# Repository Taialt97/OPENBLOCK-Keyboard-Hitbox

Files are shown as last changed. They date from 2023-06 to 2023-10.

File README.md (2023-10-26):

 

>:warning: This project is currently under development; the PCBs have not been tested and may require additional optimization.

# Introduction
This project aims to create an open-source, modular, and easy-to-understand design for a Hit Box layout using the Raspberry Pi (RP2040) as the core. My goal is to make the project as accessible and customizable as possible, providing everyone with the flexibility to adapt the design to their specific needs.

downImg
downImg(2)

## Chip Compatibility
- **GP2040 chip**: Offers higher compatibility with PC, PS4, PS3, Switch, and Xbox.

| ProMicro (Mega32U4) | RespbarryPie (GP2040) | NameOfSwitch | Action | PlayStation | Xbox |
|---|---|---|---|---|---|
| 6 | 6 | MX10 | Up | Dpad Up | Dpad Up | | |
| 14 | 20 | MX2 | Down |Dpad Down | Dpad Down | | |
| 16 | 23 | MX1 | Left | Dpad Left | Dpad Left | | |
| 15 | 22 | MX3 | Right | Dpad Right | Dpad Right | | |
| 21 | 29 | MX4 | Light Punch | Square | X | | |
| 5 | 5 | MX11 | Light Kick  | X | A | | |
| 4 | 4 | MX5 | Medium Punch| Circle | B | | |
| 20 | 28 | MX12 | Medium Kick | Triangle | Y | | |
| 18 | 26 | MX6 | Heavy Punch | L1 | LB | | |
| 19 | 27 | MX13 | Heavy Kick  | R1 | RB | | |
| 2 | 2 | MX7 | Triple Punch| L2 | LT | | |
| 3 | 3 | MX14 | Triple Kick | R2 | RT | | |
| 8 | 8 | MX8 | Select 1 | Select | Back | | |
| 7 | 7 | MX9 | Select 2 | Start | Start | | |

# Costs
The cost to build the fight-stick will depend on parts, shipping, and tools. Below is a breakdown:

1. PCB (minimum order of 5) without shipping: **$8**. Shipping will vary by location and method.
2. Parts for PCB assembly: **$25** (hot swap sockets, keys, switches, Pro Micro, and IC Sockets).
3. Tools: Varies widely, but a cost-effective approach is possible.

## Part List
### Micro Chips List
Below is a list of top-tier microcontrollers that I've found to be the best in the market. While more cost-effective alternatives are available from sites like Aliexpress (which I've personally tested and found satisfactory), the following options are slightly more expensive but come with a guarantee of proper functionality.

If you're using a different 12-pin microcontroller that you think should be included here, feel free to leave a comment!

1. [Elite-Pi - USB-C Pro Micro Replacement RP2040 Controller](https://keeb.io/collections/diy-parts/products/elite-pi-usb-c-pro-micro-replacement-rp2040)
2. [SparkFun Pro Micro - RP2040](https://www.sparkfun.com/products/18288)

### Parts List
To ensure affordability, I've listed essential parts and some alternatives:

- PCB | $8 (without shipping)
- (optional) Hot-swappable PCB socket | $3
- Keycaps | $5-$15 (depends on quality)
- Switch | $5-$50 (depends on the manufacturer and "quality" of the switch)
- Pro Micro | $4-$30 (ensure the chip is **RP2040**)

### Recommended
- KESTER SOLDER | $35-$60 (quality soldering wire)
- PINECIL – Smart Mini Portable Soldering Iron (Version 2) | $25.99-$35.99

# Code

Upon connecting the microcontroller to your computer, a new drive will appear. 
- Drag the `nuke.h` file into this drive; the microcontroller will disconnect and then reconnect.
- Drag the `OpenBlock.h` file into the drive. You'll hear a sound indicating that the drive has disconnected and reconnected.

To test your controller, visit the [Gamepad Tester Website](https://hardwaretester.com/gamepad).
For modifying the code or creating new code, go to the [GP2040-CE](https://gp2040-ce.info/#/) website.
There, you'll find all the resources you need to customize or create new code. If you have any questions, refer to our [Discord channel](https://discord.gg/kJDAZVwU) — they're awesome!

# Note
This project is an open-source initiative, designed for modularity and ease of understanding. Contributions and suggestions from the community are welcome, fostering collaboration and growth.

# Sponsorship
This repository is sponsored by [PCBWay](https://www.pcbway.com/).
PCBWay (https://www.pcbway.com/)
PCBWay specializes in manufacturing high-quality PCBs. They offer a range of services including PCB prototyping, assembly, and much more. We are grateful for their support in making this project possible.
Simplify Your Custom PCB Orders with PCBWay

Ordering custom PCBs has never been easier, thanks to PCBWay's intuitive platform. With the 'Instant Quote' feature, you can swiftly enter crucial information such as PCB type, dimensions, and material. Plus, helpful tooltips and guides are there to assist you every step of the way.
Unmatched Verification Process

What sets PCBWay apart is their meticulous verification process. Once you upload your Gerber files, a team of experts scrutinizes them for any errors or omissions. You'll be promptly notified of any issues via email or directly on the platform, ensuring a nearly error-free process.
Real-Time Project Tracking

PCBWay takes your experience up a notch by offering real-time project tracking. This level of transparency allows you to better manage your project timelines and make well-informed decisions.
Reliable and Fast Shipping

When it's time to ship, PCBWay provides trustworthy options like DHL, FedEx, and OCS. Need it fast? Expedited shipping is available right from the get-go. In a recent test run, the entire process—from uploading the Gerber files to receiving the finished PCBs—took just six days.
Conclusion

PCBWay is a top choice for anyone transitioning from generic to custom PCBs. The platform excels in ease of use, quality control, and speed, making it ideal for specialized projects.
For more information, visit their [website](https://www.pcbway.com/).

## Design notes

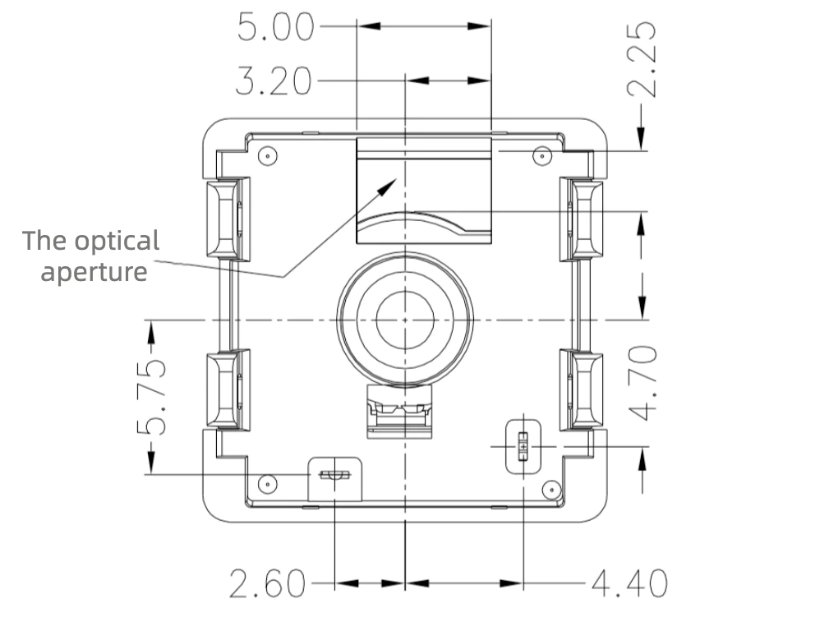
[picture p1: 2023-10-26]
Open-Block RP2040 Gateron Only Low Profile/Kicad Files/gateron-low-profile-mechanical-switch-pcb-of-layout.webp

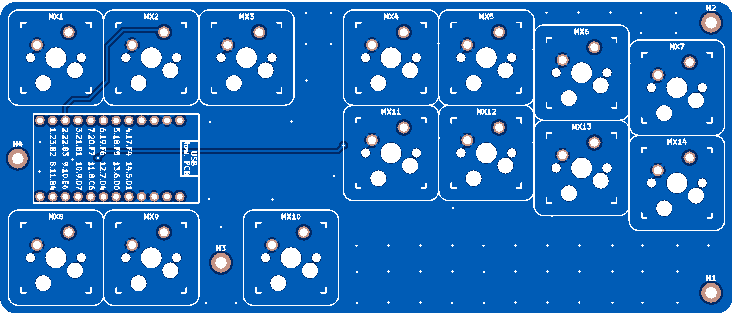
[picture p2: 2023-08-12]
Open-Block RP2040 High Profile/Images/Top.png

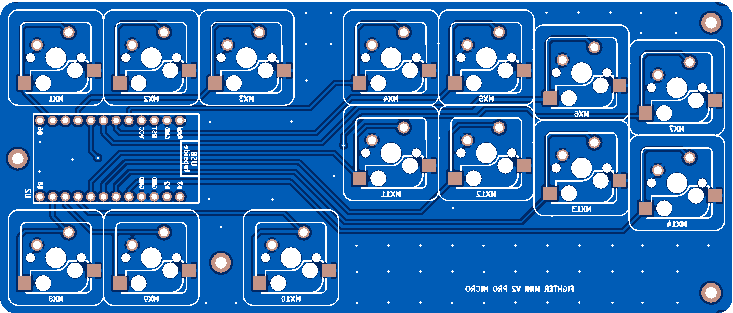
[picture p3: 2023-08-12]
Open-Block RP2040 High Profile/Images/Bottom.png

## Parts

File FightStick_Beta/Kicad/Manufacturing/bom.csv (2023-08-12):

Designator | Footprint | Quantity | Value | LCSC Part #
C2 | 0805 | 1 | 4.7uF | CC0805ZRY5V6BB475
C3 | 0805 | 1 | 0.1uF | CC0805ZRY5V6BB475
D1, D10, D11, D12, D13, D14, D2, D3, D4, D5, D6, D7, D8, D9 | D_SOD-123 | 14 | 1N4448W-TP | 1N4448W-TP
H1, H2, H3 | MountingHole_4.3mm_M4 | 3 | MountingHole
J1 | JST_PH_B2B-PH-K_1x02_P2.00mm_Vertical | 1 | B2B-PH-K-S(LF)(SN) | B2B-PH-K-S(LF)(SN)
MX1, MX10, MX11, MX12, MX13, MX14, MX2, MX3, MX4, MX5, MX6, MX7, MX8, MX9 | Kailh_socket_MX_optional | 14 | MX_SW_solder
R3 | 0805 | 1 | 100k | RC0805JR-07100KL
SW2 | SW_EG2208 | 1 | EG2208
U1 | ArduinoProMicro | 1 | ProMicro

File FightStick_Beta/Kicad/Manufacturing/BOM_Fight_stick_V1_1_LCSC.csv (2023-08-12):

Designator | Footprint | Quantity | Value | Part # | LCSC Part #
C2 | 805 | 1 | 4.7uF | CC0805KKX7R8BB475 | C354262
C3 | 805 | 1 | 0.1uF | CC0805KRX7R9BB104 | C49678
D1, D10, D11, D12, D13, D14, D2, D3, D4, D5, D6, D7, D8, D9 | D_SOD-123 | 14 | 1N4448W-TP | 1N4448W-TP | C668855
J1 | JST_PH_B2B-PH-K_1x02_P2.00mm_Vertical | 1 | B2B-PH-K-S(LF)(SN) | B2B-PH-K-S(LF)(SN) | C131337
MX1, MX10, MX11, MX12, MX13, MX14, MX2, MX3, MX4, MX5, MX6, MX7, MX8, MX9 | Kailh_socket_MX_optional | 14 | MX_SW_solder | Kailh CPG151101D212 | C400234
R3 | 805 | 1 | 100k | RC0805FR-07100KL | C96346
SW2 | SW_EG2208 | 1 | EG2208 |  | C609827
U1 | ArduinoProMicro | 1 | ProMicro | custom module

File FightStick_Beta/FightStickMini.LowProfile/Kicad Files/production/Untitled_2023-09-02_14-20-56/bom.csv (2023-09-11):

Designator | Footprint | Quantity | Value | LCSC Part #
H1, H2, H3, H4 | MountingHole_2.2mm_M2_DIN965_Pad | 4 | MountingHole
MX1, MX10, MX11, MX12, MX13, MX14, MX2, MX3, MX4, MX5, MX6, MX7, MX8, MX9 | Kailh_socket_PG1350_optional | 14 | MX_SW_HS

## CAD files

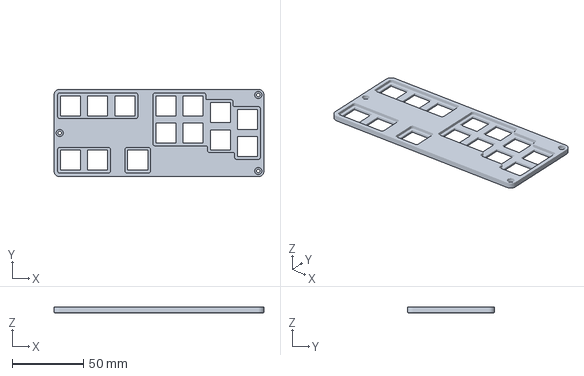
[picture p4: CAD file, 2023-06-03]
FightStick_Beta/Fusion 360/Plate.3mf
146.9 x 61.1 x 4.00 mm

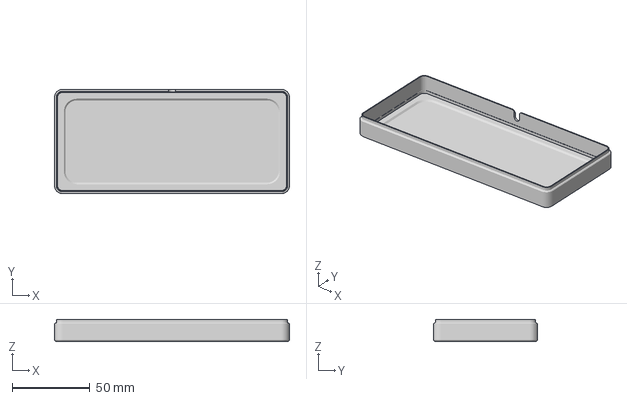
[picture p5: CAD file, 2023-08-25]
Open-Block RP2040 High Profile/3DFiles/BottomCase.3mf
151.2 x 67.1 x 14.3 mm

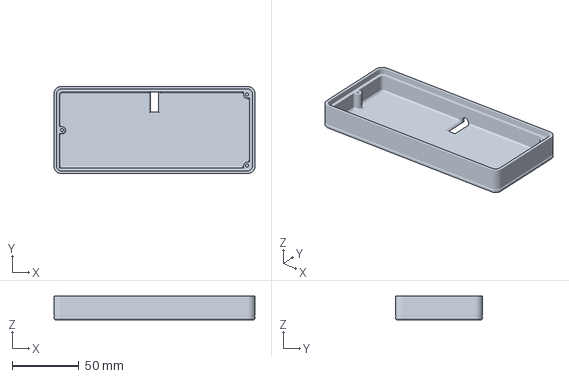
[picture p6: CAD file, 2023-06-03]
FightStick_Beta/Fusion 360/Case.3mf
150.9 x 65.1 x 18.0 mm

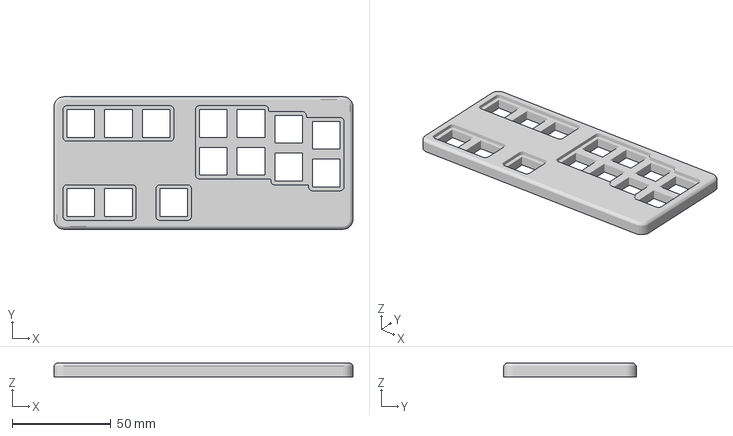
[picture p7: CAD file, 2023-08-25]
Open-Block RP2040 High Profile/3DFiles/TopCase.3mf
151.2 x 67.1 x 7.00 mm

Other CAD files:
FightStick_Beta/Fusion 360/Case.stl
FightStick_Beta/Fusion 360/Fight Stick Fusion 360.f3d
FightStick_Beta/Fusion 360/Plate.stl
Open-Block RP2040 High Profile/3DFiles/FightStickMiniCase.f3z

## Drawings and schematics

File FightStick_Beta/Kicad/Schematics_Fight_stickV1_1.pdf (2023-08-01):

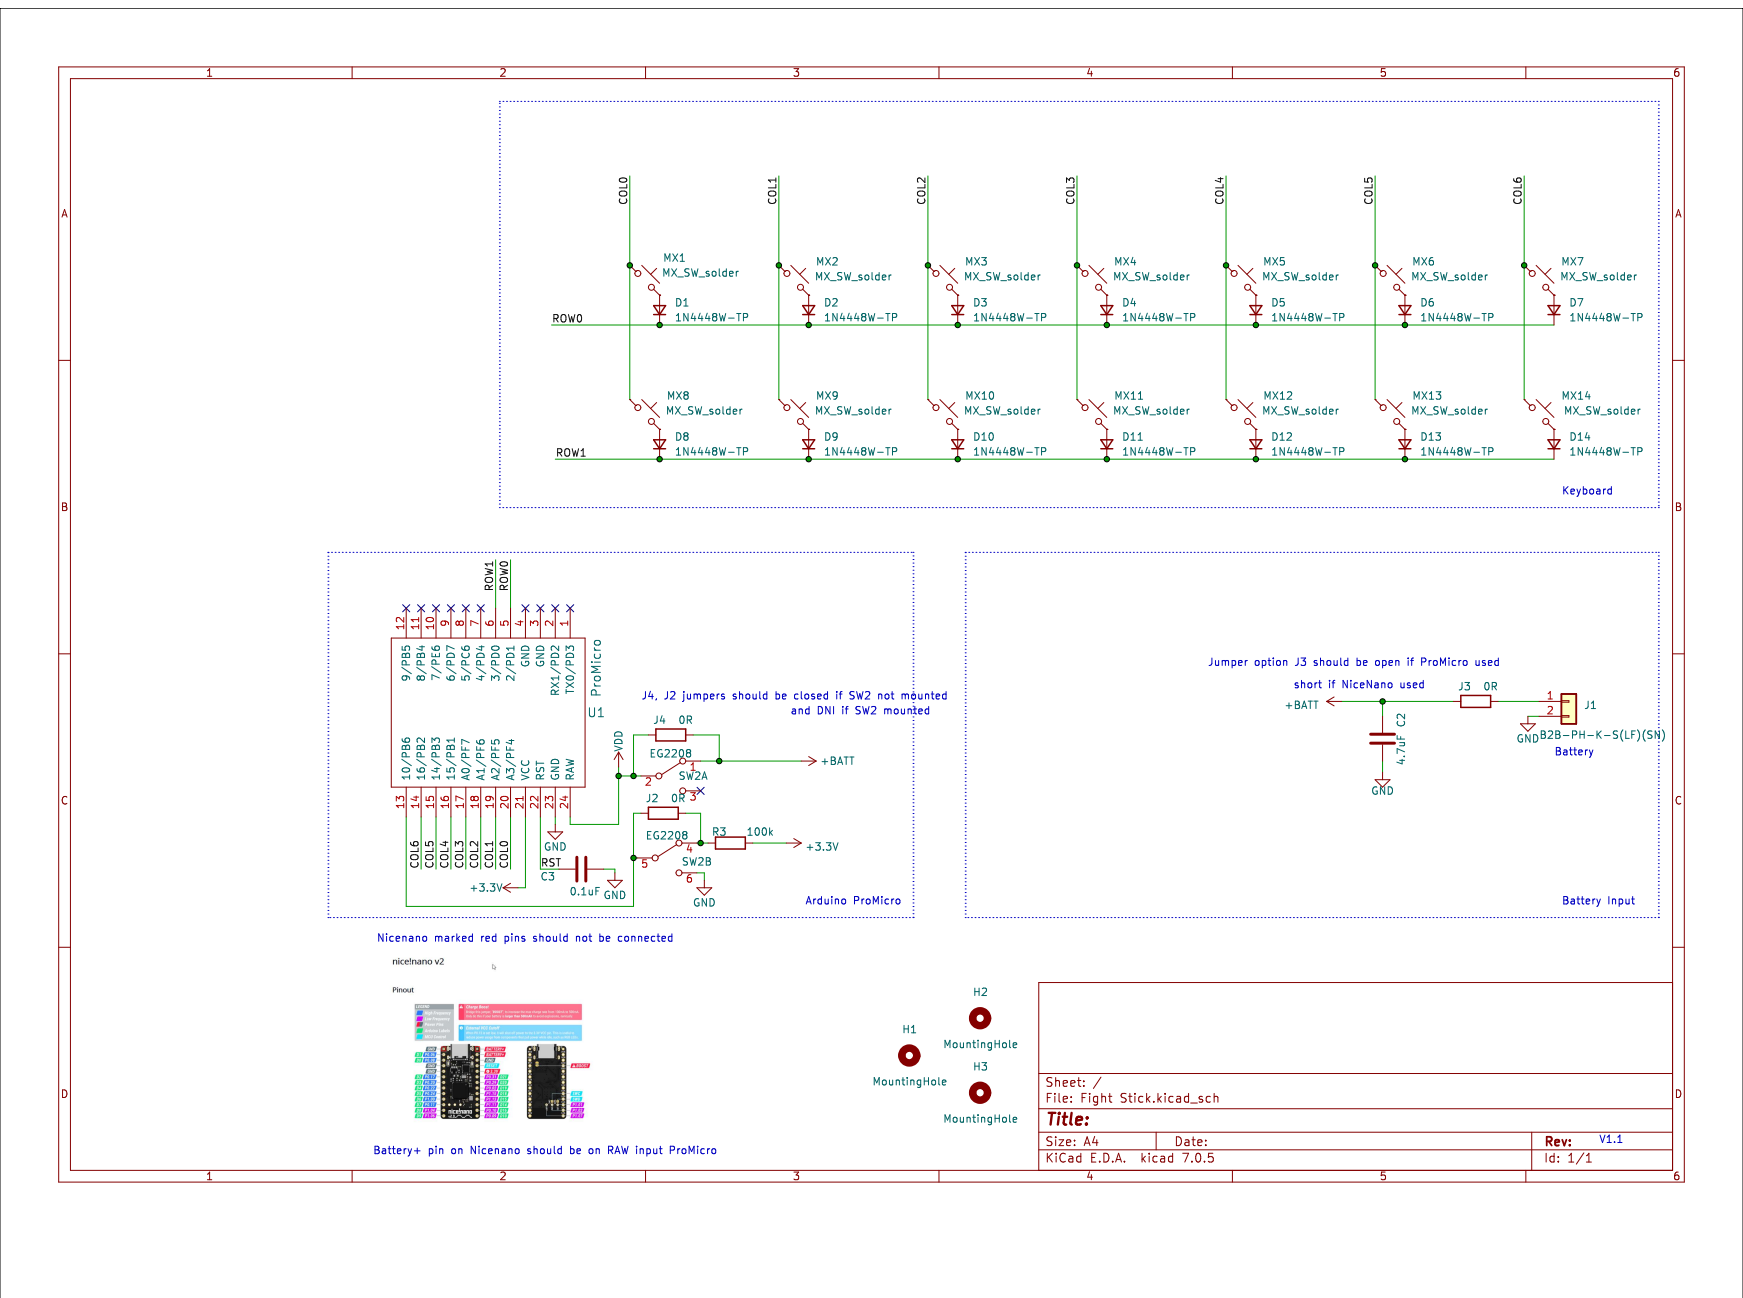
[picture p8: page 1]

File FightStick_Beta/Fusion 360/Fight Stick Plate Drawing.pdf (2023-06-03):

61.15 137.82

52.1 A A (2:1) | 14 TYP

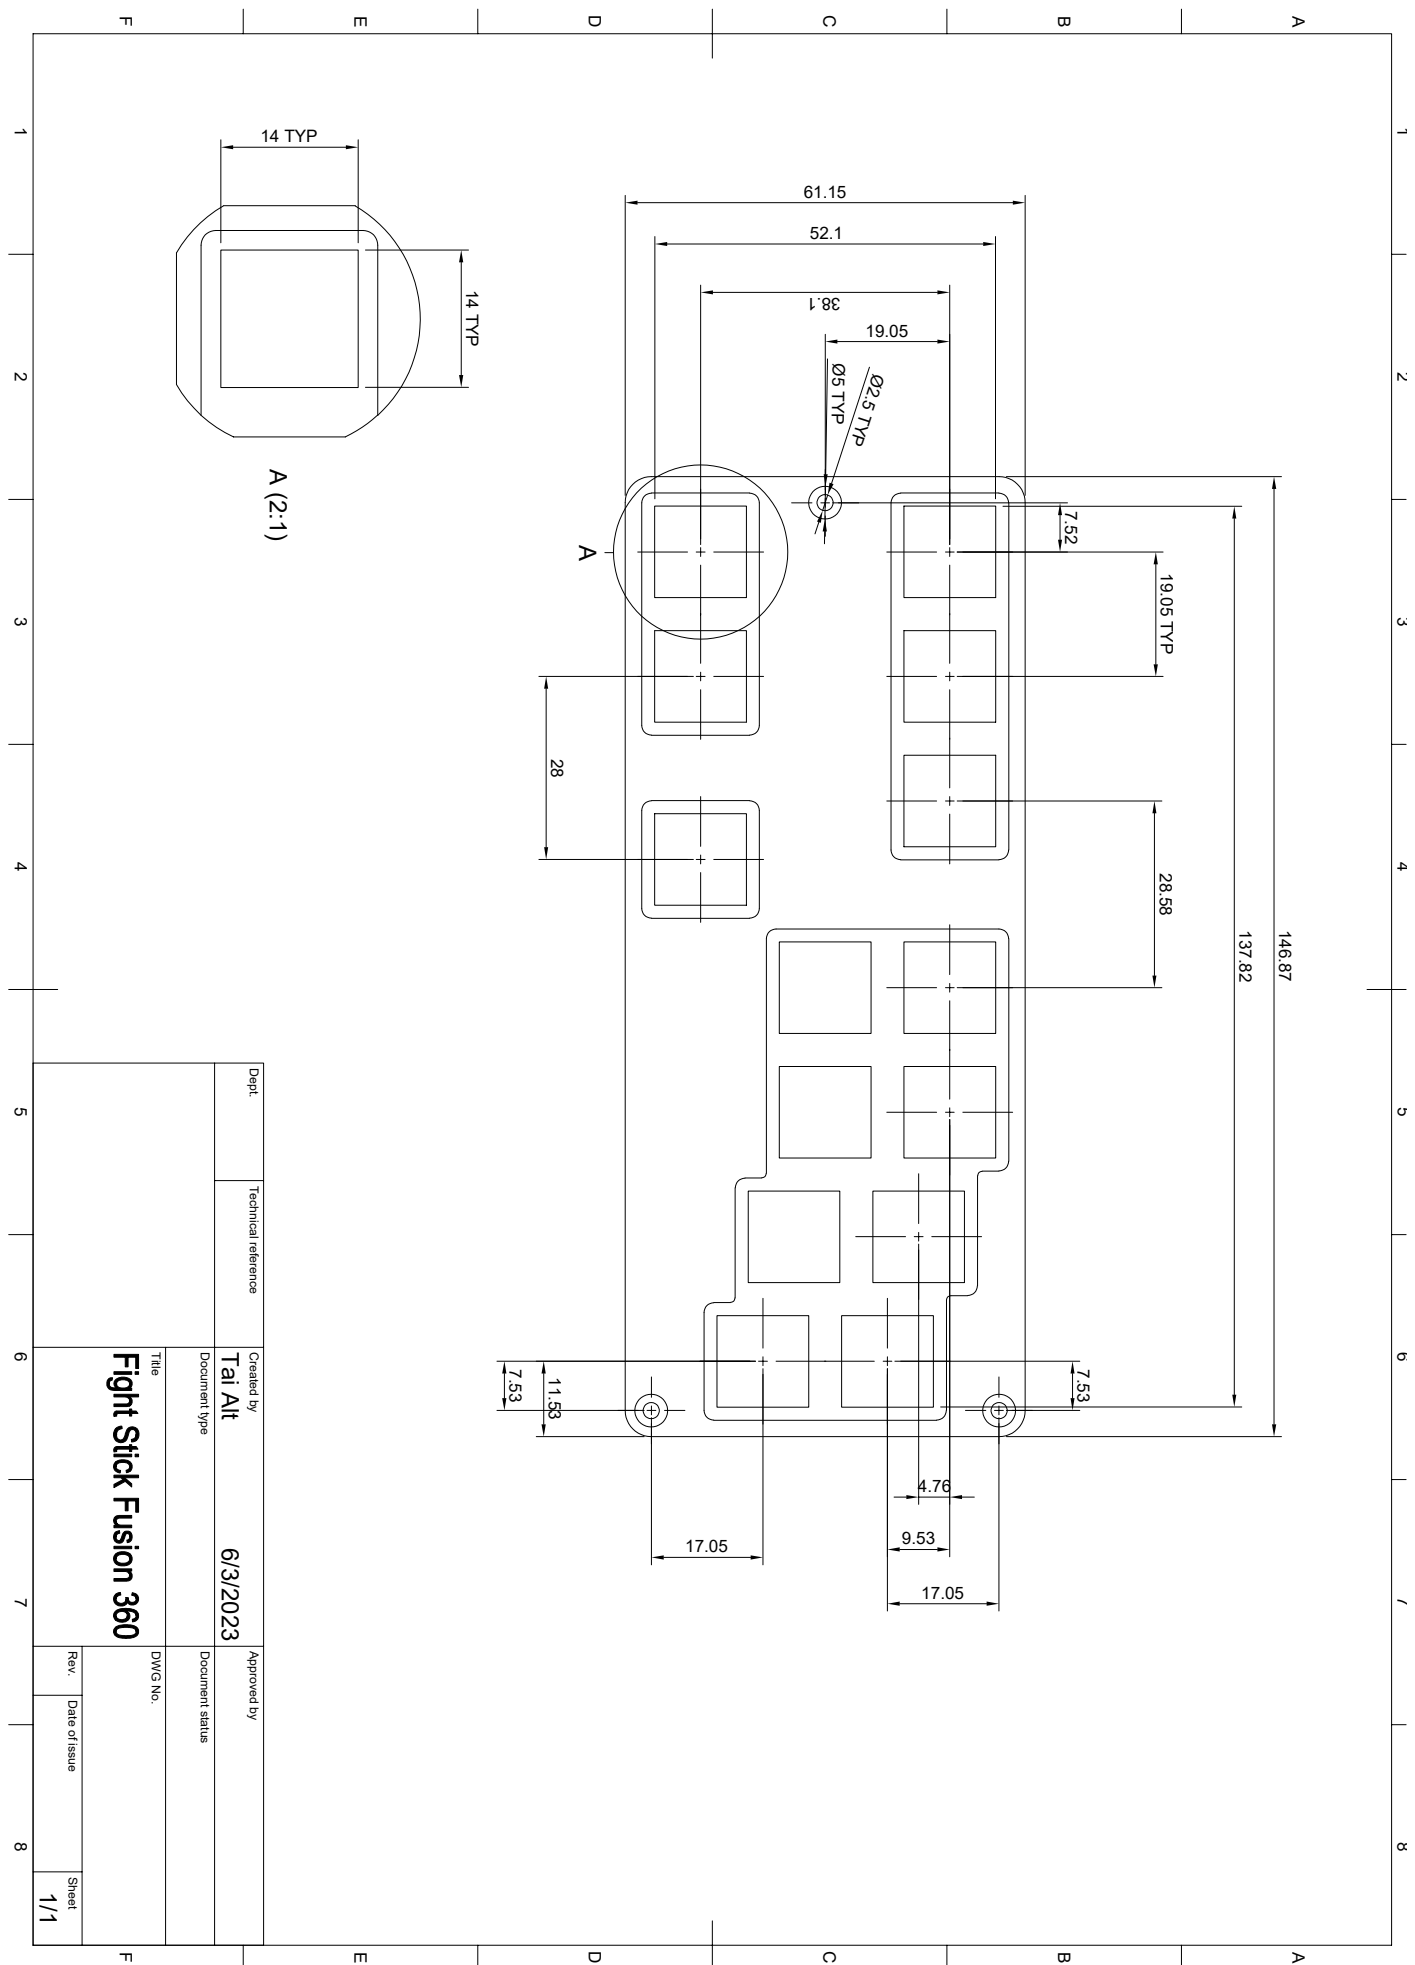
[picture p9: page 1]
14 TYP; 19.05 TYP 28

1 A 2 3 4 5 6 7 8 1 2 3 4 5 6 7 8 FEDCB FEDCBA Dept. Technical reference Created by Approved by Title DWG No. Document type Document status Rev. Date of issue Sheet 6/3/2023 1/1 Tai Alt 146.87

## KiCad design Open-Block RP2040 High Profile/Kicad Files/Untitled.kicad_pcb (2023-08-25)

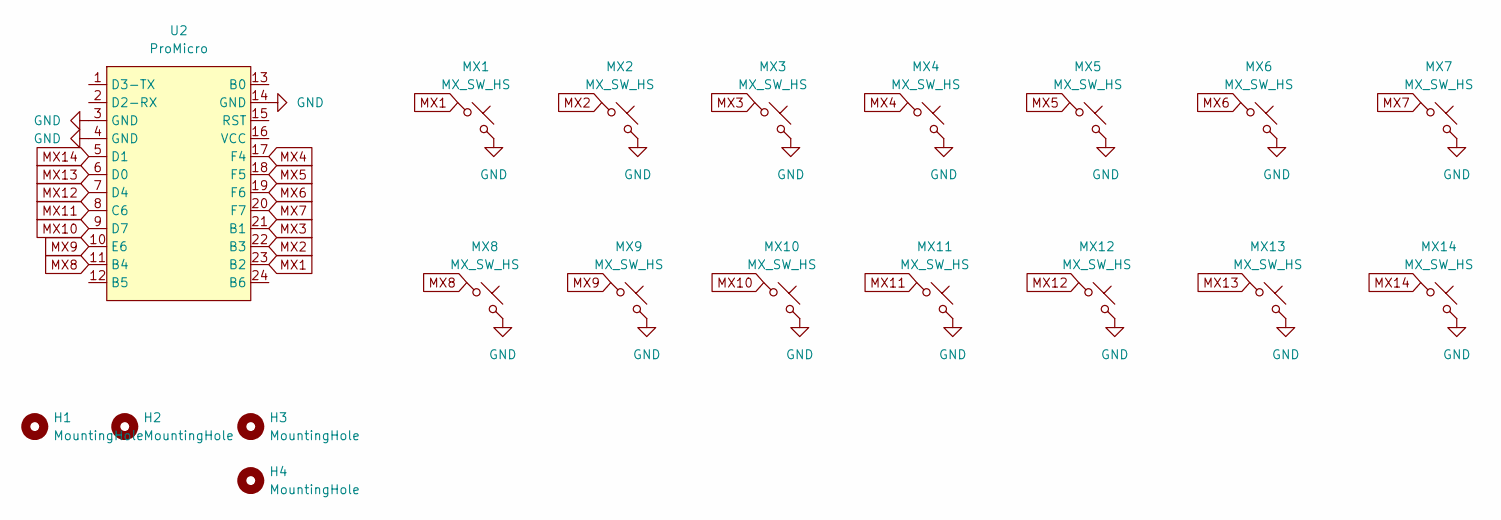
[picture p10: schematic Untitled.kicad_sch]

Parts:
H1, H2, H3, H4: MountingHole; MountingHole_2.2mm_M2_DIN965_Pad
MX1, MX2, MX3, MX4, MX5, MX6, MX7, MX8, MX9, MX10, MX11, MX12, MX13, MX14: MX_SW_HS; MX_optional
U2: ProMicro; ProMicro_USBdn

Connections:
GND: MX1.2, MX2.2, MX3.2, MX4.2, MX5.2, MX6.2, MX7.2, MX8.2, MX9.2, MX10.2, MX11.2, MX12.2, MX13.2, MX14.2, U2.3 (GND), U2.4 (GND), U2.14 (GND)
MX1: MX1.1, U2.23 (B2)
MX2: MX2.1, U2.22 (B3)
MX3: MX3.1, U2.21 (B1)
MX4: MX4.1, U2.17 (F4)
MX5: MX5.1, U2.18 (F5)
MX6: MX6.1, U2.19 (F6)
MX7: MX7.1, U2.20 (F7)
MX8: MX8.1, U2.11 (B4)
MX9: MX9.1, U2.10 (E6)
MX10: MX10.1, U2.9 (D7)
MX11: MX11.1, U2.8 (C6)
MX12: MX12.1, U2.7 (D4)
MX13: MX13.1, U2.6 (D0)
MX14: MX14.1, U2.5 (D1)

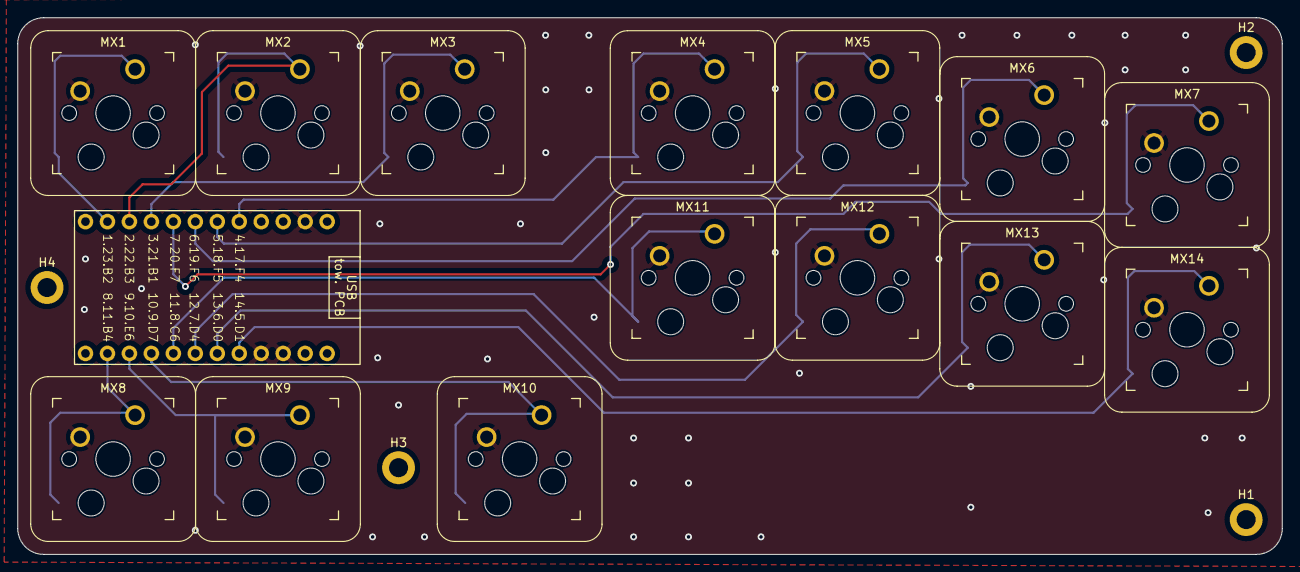
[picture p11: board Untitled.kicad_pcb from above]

Board: 2 copper layers, 146.2 x 62.1 mm, 19 parts (1 on the bottom side), 15 nets.

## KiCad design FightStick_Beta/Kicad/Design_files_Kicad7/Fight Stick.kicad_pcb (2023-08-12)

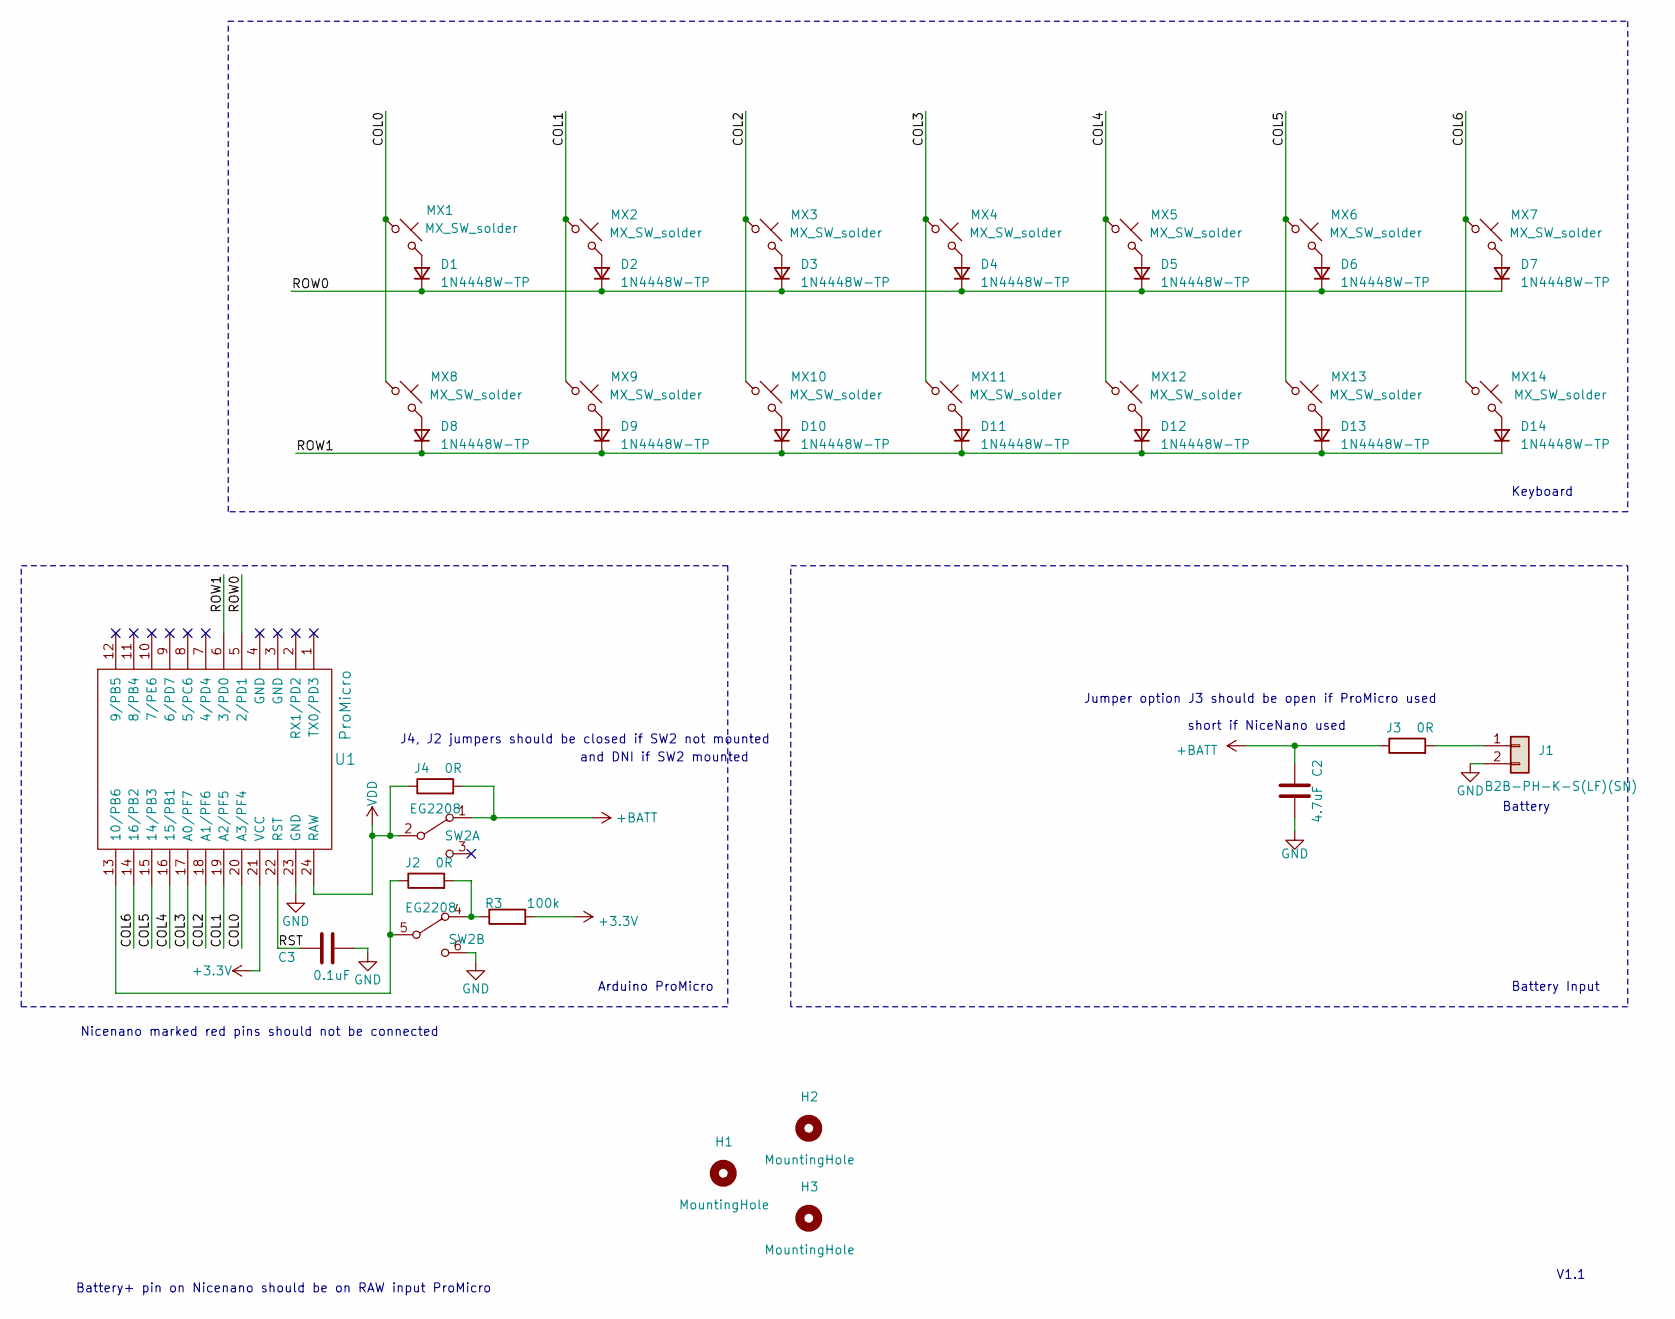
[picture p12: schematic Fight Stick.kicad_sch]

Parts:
C2: 4.7uF; C_0805_2012Metric; MPN CC0805ZRY5V6BB475; Digikey PN 311-1371-1-ND
C3: 0.1uF; C_0805_2012Metric; MPN CC0805ZRY5V6BB475; Digikey PN 311-1371-1-ND
D1, D2, D3, D4, D5, D6, D7, D8, D9, D10, D11, D12, D13, D14: 1N4448W-TP; D_SOD-123; MPN 1N4448W-TP; Digikey PN 1N4448WTPMSCT-ND
H1, H2, H3: MountingHole; MountingHole_4.3mm_M4
J1: B2B-PH-K-S(LF)(SN); JST_PH_B2B-PH-K_1x02_P2.00mm_Vertical; MPN B2B-PH-K-S(LF)(SN); Digikey PN 455-1704-ND
J2, J3, J4: 0R; R_0805_2012Metric; MPN RC0805FR-070RL; Digikey PN 311-0.0CRCT-ND
MX1, MX2, MX3, MX4, MX5, MX6, MX7, MX8, MX9, MX10, MX11, MX12, MX13, MX14: MX_SW_solder; Kailh_socket_MX_optional
R3: 100k; R_0805_2012Metric; MPN RC0805JR-07100KL; Digikey PN 311-100KARCT-ND
SW2: EG2208; SW_EG2208
U1: ProMicro; ArduinoProMicro

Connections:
+3.3V: R3.2, U1.21 (VCC)
+BATT: C2.1, J3.1, J4.2, SW2.1 (A)
/COL0: MX1.1, MX8.1, U1.20 (A3/PF4)
/COL1: MX2.1, MX9.1, U1.19 (A2/PF5)
/COL2: MX3.1, MX10.1, U1.18 (A1/PF6)
/COL3: MX4.1, MX11.1, U1.17 (A0/PF7)
/COL4: MX5.1, MX12.1, U1.16 (15/PB1)
/COL5: MX6.1, MX13.1, U1.15 (14/PB3)
/COL6: MX7.1, MX14.1, U1.14 (16/PB2)
/ROW0: D1.1 (K), D2.1 (K), D3.1 (K), D4.1 (K), D5.1 (K), D6.1 (K), D7.1 (K), U1.5 (2/PD1)
/ROW1: D8.1 (K), D9.1 (K), D10.1 (K), D11.1 (K), D12.1 (K), D13.1 (K), D14.1 (K), U1.6 (3/PD0)
/RST: C3.1, U1.22 (RST)
GND: C2.2, C3.2, J1.2, SW2.6 (C), U1.23 (GND)
unnamed: D1.2 (A), MX1.2
unnamed: D2.2 (A), MX2.2
unnamed: D3.2 (A), MX3.2
unnamed: D4.2 (A), MX4.2
unnamed: D5.2 (A), MX5.2
unnamed: D6.2 (A), MX6.2
unnamed: D7.2 (A), MX7.2
unnamed: D8.2 (A), MX8.2
unnamed: D9.2 (A), MX9.2
unnamed: D10.2 (A), MX10.2
unnamed: D11.2 (A), MX11.2
unnamed: D12.2 (A), MX12.2
unnamed: D13.2 (A), MX13.2
unnamed: D14.2 (A), MX14.2
unnamed: J1.1, J3.2
unnamed: J2.2, R3.1, SW2.4 (A)
unnamed: J2.1, SW2.5 (B), U1.13 (10/PB6)
VDD: J4.1, SW2.2 (B), U1.24 (RAW)

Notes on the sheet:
Battery
Keyboard
Battery Input
Battery+ pin on Nicenano should be on RAW input ProMicro
V1.1
and DNI if SW2 mounted
Arduino ProMicro
J4, J2 jumpers should be closed if SW2 not mounted
Jumper option J3 should be open if ProMicro used
Nicenano marked red pins should not be connected
short if NiceNano used

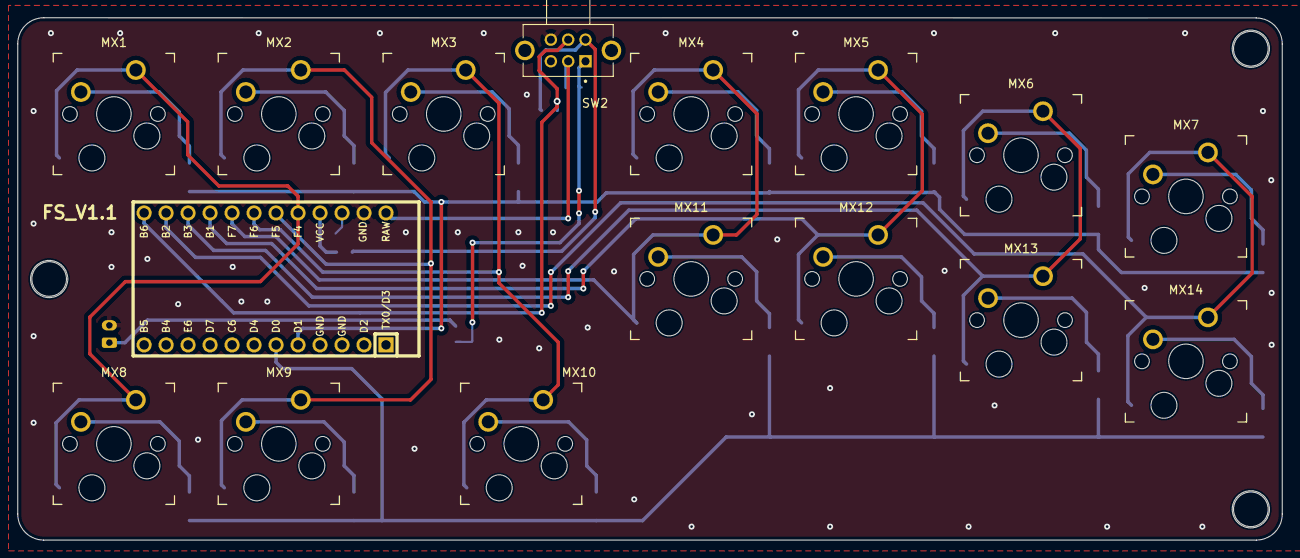
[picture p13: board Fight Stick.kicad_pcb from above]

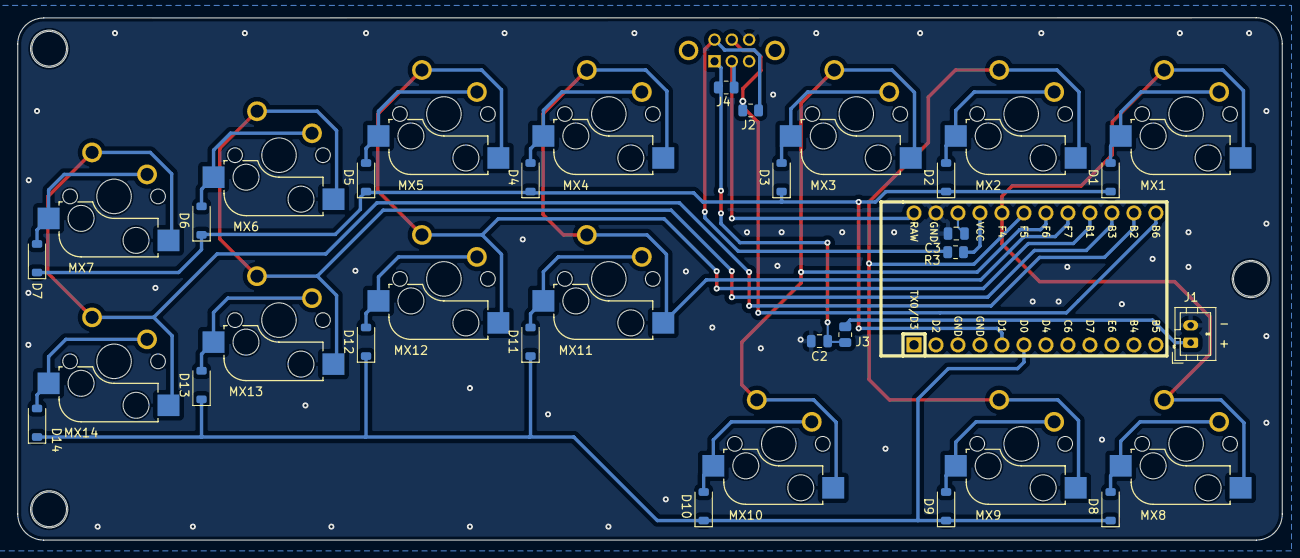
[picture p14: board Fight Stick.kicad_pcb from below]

Board: 2 copper layers, 146.1 x 60.3 mm, 40 parts (22 on the bottom side), 31 nets.

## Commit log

2023-06-03 Added Fusion 360 Files
    [Case.3mf, Case.stl, Fight Stick Fusion 360.f3d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]
2023-08-10 fight stick 2 direct
    [CON_2121340002.step, CON_2121340003.step, CON_2121340004.step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]
2023-08-11 second version upload
    [Untitled.kicad_pcb, Untitled.kicad_sch]
2023-08-12 Version 2
    [BOM_Fight_stick_V1_1_LCSC.csv, BOM_Fight_stick_V1_1_LCSC.xlsx, CON_2121340002.step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]

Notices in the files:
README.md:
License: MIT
